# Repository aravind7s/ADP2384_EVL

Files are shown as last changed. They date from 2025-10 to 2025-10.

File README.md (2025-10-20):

# ADP2384_EVL

Hardware design files for a **12 V → 3.3 V @ 4 A** DC-DC buck converter based on the **Analog Devices ADP2384** designed using KiCad.

---

## 🧭 Overview

This project contains the complete design package — schematic, layout, and simulation files — for a compact, high-efficiency step-down converter using the ADP2384 synchronous buck regulator.  

---

## ⚙️ Board Specifications

| Parameter | Specification |
|---|---|
| Input Voltage | 12 V |
| Output Voltage | 3.3 V |
| Output Current | Up to 4 A |
| Regulator IC | ADP2384 |
| Board Dimensions | 35 mm × 40 mm |
| PCB Layers | 2 layers |
| Assembly | Single-sided |

---

*3D render of the ADP2384_EVL board (35 × 40 mm)*

*Front Side*

<p align="left">
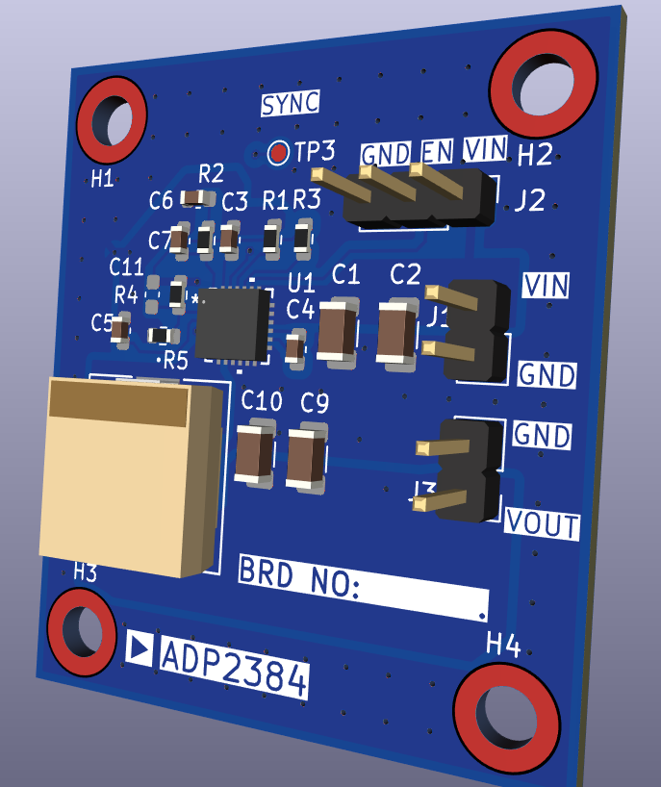
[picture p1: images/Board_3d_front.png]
3D View of the Board Front Side
  
</p>

*Back Side*

<p align="left">
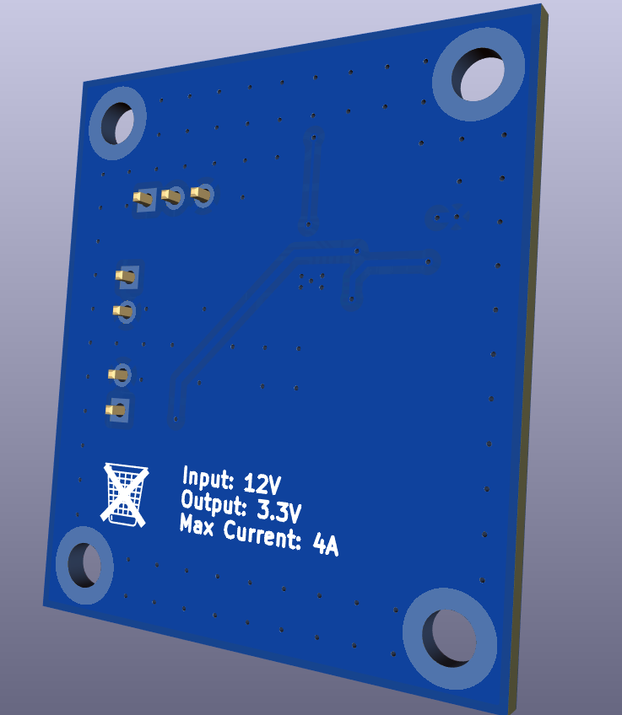
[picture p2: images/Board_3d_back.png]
3D View of the Board Back Side
  
</p>

---

## 📂 Repository Structure
/

├── Board_Files/ # Schematics, BOM, PCB layout and Gerbers

├── Simulation_Files/ # LTspice file

├── TechRef/ # Datasheets and application notes

├── images/ # Renders, photos, documentation images

├── LICENSE

└── README.md

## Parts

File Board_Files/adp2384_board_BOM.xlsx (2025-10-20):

S. No | Reference | Description | Mfg | Mfg Part No | Value | Qty | Footprint | Datasheet
1 | C1,C2 | Cap, Cer-X7R, 10uF, 25Vdc, 10%, 1206 | Samsung Electro-Mechanics | CL31B106KAHNNNE | 10uF | 2 | Capacitor_SMD:C_1206_3216Metric | https://product.samsungsem.com/mlcc/CL31B106KAHNNN.do
2 | C3 | Cap, Cer-X7R, 22nF, 100Vdc, 10%, 0603 | Murata Electronics | GCM188R72A223KA37J | 22nF | 1 | Capacitor_SMD:C_0603_1608Metric | https://pim.murata.com/en-sg/pim/details/?partNum=GCM188R72A223KA37%23
3 | C4 | Cap, Cer-X7R, 0.1uF, 50Vdc, 10%, 0603 | YAGEO | CC0603KRX7R9BB104 | 0.1uF | 1 | Capacitor_SMD:C_0603_1608Metric | yageo.com/en/Chart/Download/pdf/CC0603KRX7R7BB104
4 | C5 | Cap, Cer-X7R, 1uF, 16Vdc, 10%, 0603 | Samsung Electro-Mechanics | CL10B105KO8NNNC | 1uF | 1 | Capacitor_SMD:C_0603_1608Metric | https://weblib.samsungsem.com/mlcc/mlcc-ec-data-sheet.do?partNumber=CL10B105KO8NNN
5 | C6 | Cap, Cer-C0G, 1500pF, 50Vdc, 5%, 0603 | Murata Electronics | GRM1885C1H152JA01D | 1500pF | 1 | Capacitor_SMD:C_0603_1608Metric | https://pim.murata.com/en-eu/pim/details/?partNum=GRM1885C1H152JA01D
6 | C7 | Cap, Cer-C0G, 4.7pF, 50Vdc, +/-0.25pF, 0603 | YAGEO | CC0603CPNPO9BN4R7 | 4.7pF | 1 | Capacitor_SMD:C_0603_1608Metric | https://www.yageogroup.com/download/specsheet/CC0603CRNPO9BN4R7
7 | C9,C10 | Cap, Cer-X5R, 47uF, 10Vdc, 20%, 1206 | Murata Electronics | GRM31CR61A476ME15L | 47uF | 2 | Capacitor_SMD:C_1206_3216Metric | https://pim.murata.com/en-sg/pim/details/?partNum=GRM31CR61A476ME15%23
8 | J1,J3 | Conn, Header, Male, 1x2, 2.54mm, Vertical, TH | Adam Tech | PH1-02-UA | Conn_01x02 | 2 | Connector_PinHeader_2.54mm:PinHeader_1x02_P2.54mm_Vertical | https://app.adam-tech.com/products/download/data_sheet/201605/ph1-xx-ua-data-sheet.pdf
9 | J2 | Conn, Header, Male, 1x3, 2.54mm, Vertical, TH | Adam Tech | PH1-03-UA | Conn_01x03 | 1 | Connector_PinHeader_2.54mm:PinHeader_1x03_P2.54mm_Vertical | https://app.adam-tech.com/products/download/data_sheet/201605/ph1-xx-ua-data-sheet.pdf
10 | L1 | Ind, 3.3uH, 20%, 18.6A, 14.4mE, Shielded, SMD | Vishay Dale | IHLP4040DZER3R3M01 | 3.3uH | 1 | IHLP-4040DZ-01:IND_IHLP-4040DZ_VIS | https://www.vishay.com/docs/34193/ihlp-4040dz-01.pdf
11 | R1 | Res, Chip, 100k, 1%, 1/8W, AEC-Q200, 0603 | Vishay Dale | CRCW0603100KFKEA | 100k | 1 | Resistor_SMD:R_0603_1608Metric | https://www.vishay.com/docs/20035/dcrcwe3.pdf
12 | R2 | Res, Chip, 31.6k, 1%, 1/8W, AEC-Q200, 0603 | Vishay Dale | CRCW060331K6FKEA | 31.6k | 1 | Resistor_SMD:R_0603_1608Metric | https://www.vishay.com/docs/20035/dcrcwe3.pdf
13 | R3,R4 | Res, Chip, 10k, 1%, 1/8W, AEC-Q200, 0603 | Vishay Dale | CRCW060310K0FKEA | 10k | 2 | Resistor_SMD:R_0603_1608Metric | https://www.vishay.com/docs/20035/dcrcwe3.pdf
14 | R5 | Res, Chip, 2.21k, 1%, 1/8W, AEC-Q200, 0603 | Vishay Dale | CRCW06032K21FKEA | 2.21k | 1 | Resistor_SMD:R_0603_1608Metric | https://www.vishay.com/docs/20035/dcrcwe3.pdf
15 | U1 | IC, Power, 0.45V-20V, 0.6-18V, 4A, QFN-24 | Analog Devices Inc. | ADP2384ACPZN-R7 | ADP2384 | 1 | ADP2384:CP_24_12_ADI | https://www.analog.com/media/en/technical-documentation/data-sheets/ADP2384.pdf

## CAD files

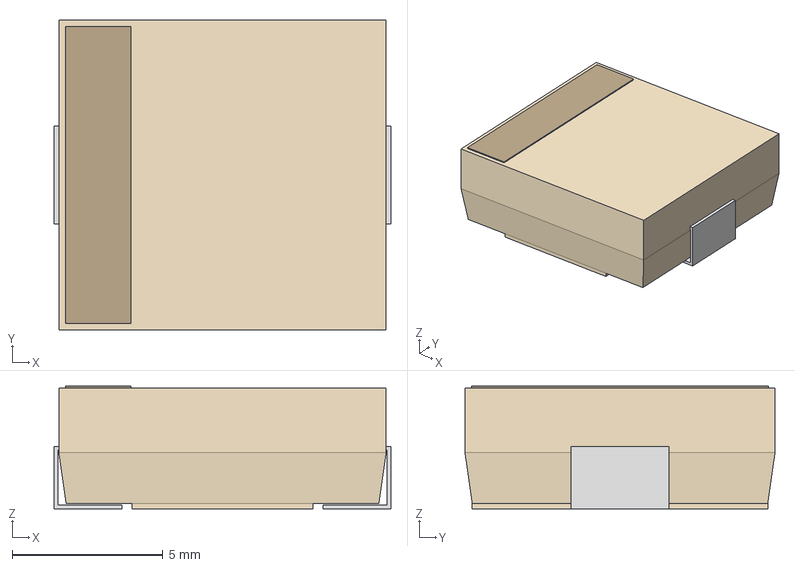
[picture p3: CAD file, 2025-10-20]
Board_Files/PartLibrary/IHLP4040DZER3R3M01/IND_IHLP-4040DZ_VIS.step
11.2 x 10.3 x 4.06 mm

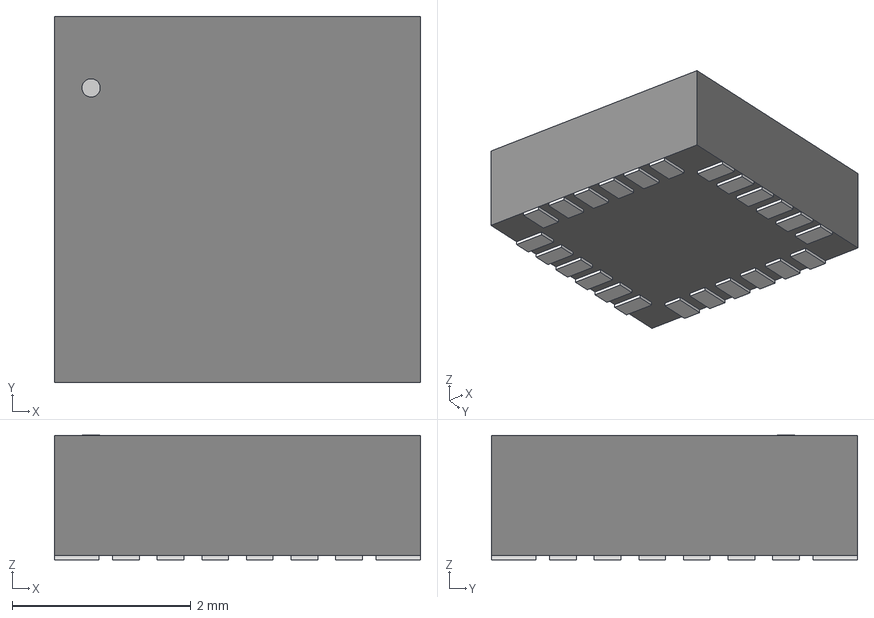
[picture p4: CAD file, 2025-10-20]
Board_Files/PartLibrary/ul_ADP2384ACPZN-R7/CP_24_12_ADI.step
4.10 x 4.10 x 1.40 mm

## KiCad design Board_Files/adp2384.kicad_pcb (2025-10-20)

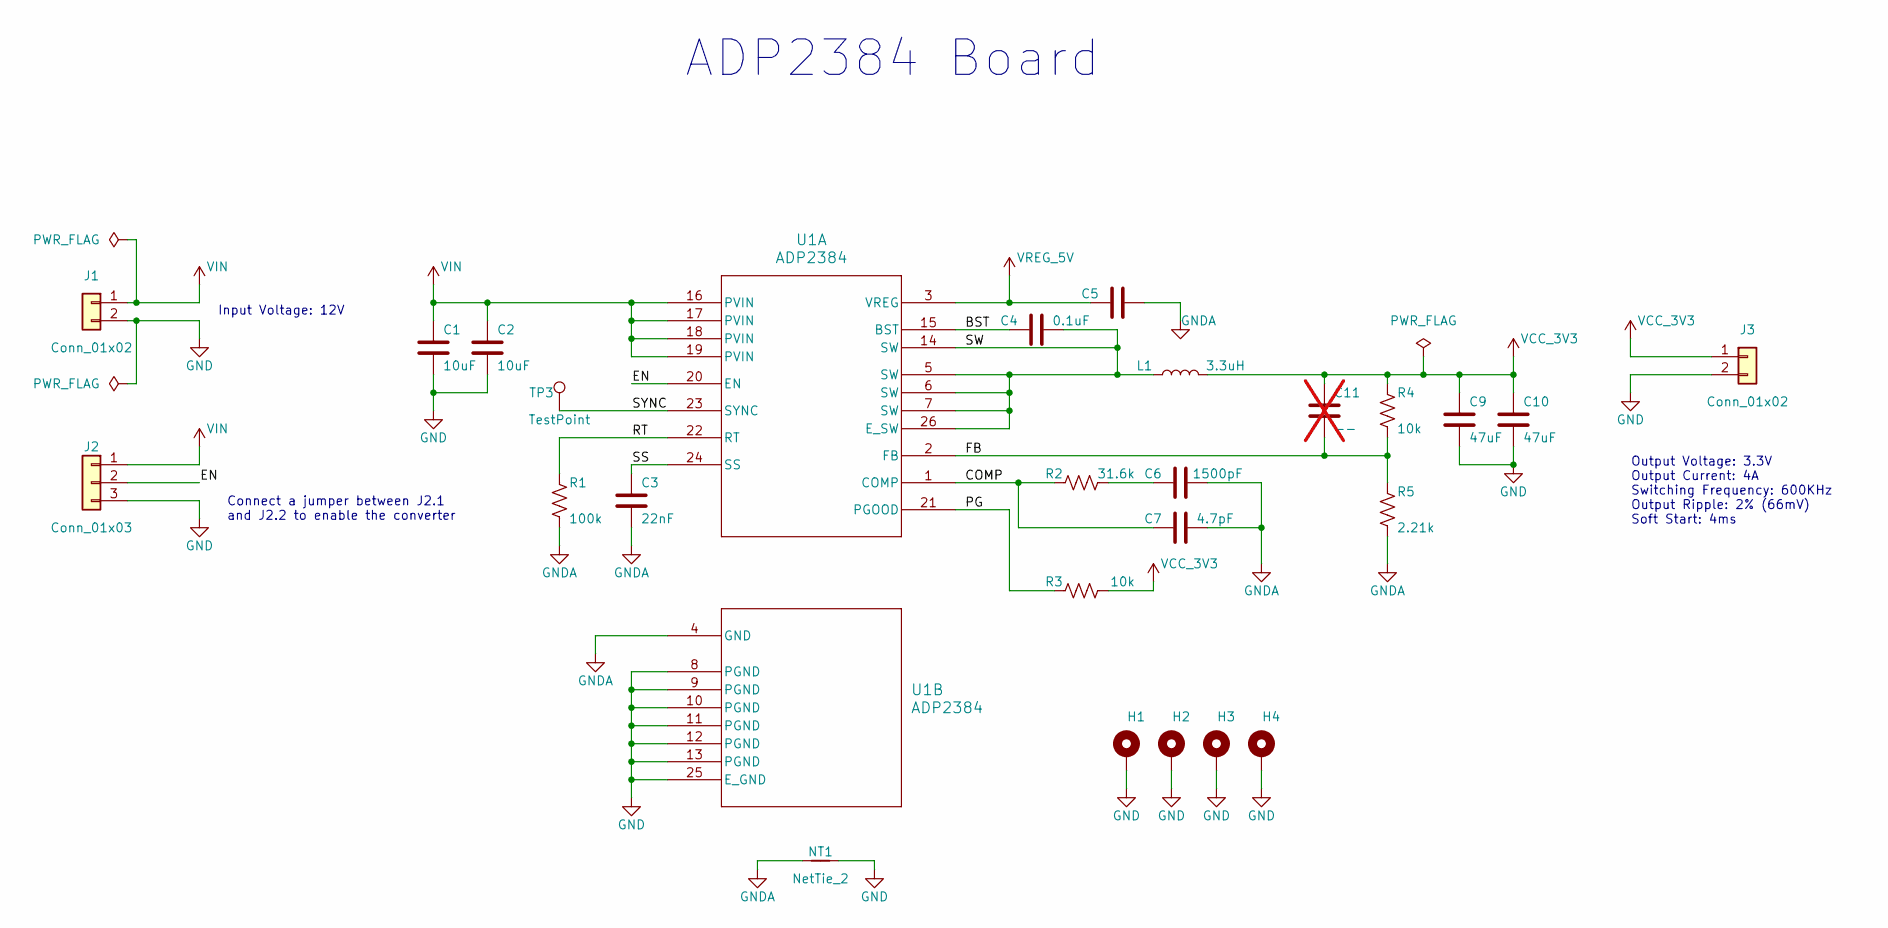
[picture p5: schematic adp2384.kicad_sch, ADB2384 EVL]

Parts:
C1, C2: 10uF; C_1206_3216Metric; Mfg Part No CL31B106KAHNNNE
C3: 22nF; C_0603_1608Metric; Mfg Part No GCM188R72A223KA37J
C4: 0.1uF; C_0603_1608Metric; Mfg Part No CC0603KRX7R9BB104
C5: 1uF; C_0603_1608Metric; Mfg Part No CL10B105KO8NNNC
C6: 1500pF; C_0603_1608Metric; Mfg Part No GRM1885C1H152JA01D
C7: 4.7pF; C_0603_1608Metric; Mfg Part No CC0603CPNPO9BN4R7
C9, C10: 47uF; C_1206_3216Metric; Mfg Part No GRM31CR61A476ME15L
C11: --; C_0603_1608Metric; Mfg Part No NA; not fitted
H1, H2, H3, H4: MountingHole_Pad; MountingHole_3.2mm_M3_DIN965_Pad_TopBottom; Mfg Part No NA
J1, J3: Conn_01x02; PinHeader_1x02_P2.54mm_Vertical; Mfg Part No PH1-02-UA
J2: Conn_01x03; PinHeader_1x03_P2.54mm_Vertical; Mfg Part No PH1-03-UA
L1: 3.3uH; IND_IHLP-4040DZ_VIS; Mfg Part No IHLP4040DZER3R3M01
NT1: NetTie_2; NetTie-2_THT_Pad0.3mm; Mfg Part No NA
R1: 100k; R_0603_1608Metric; Mfg Part No CRCW0603100KFKEA
R2: 31.6k; R_0603_1608Metric; Mfg Part No CRCW060331K6FKEA
R3, R4: 10k; R_0603_1608Metric; Mfg Part No CRCW060310K0FKEA
R5: 2.21k; R_0603_1608Metric; Mfg Part No CRCW06032K21FKEA
TP3: TestPoint; TestPoint_Pad_D1.0mm; Mfg Part No NA
U1: ADP2384; CP_24_12_ADI; Mfg Part No ADP2384ACPZN-R7

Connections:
/BST: C4.2, U1.15 (BST)
/COMP: C7.2, R2.1, U1.1 (COMP)
/EN: J2.2, U1.20 (EN)
/FB: C11.1, R4.2, R5.1, U1.2 (FB)
/PG: R3.1, U1.21 (PGOOD)
/RT: R1.1, U1.22 (RT)
/SS: C3.2, U1.24 (SS)
/SW: C4.1, L1.1, U1.5 (SW), U1.6 (SW), U1.7 (SW), U1.14 (SW), U1.26 (E_SW)
/SYNC: TP3.1, U1.23 (SYNC)
GND: C1.1, C2.1, C9.1, C10.1, H1.1, H2.1, H3.1, H4.1, J1.2, J2.3, J3.2, NT1.2, U1.8 (PGND), U1.9 (PGND), U1.10 (PGND), U1.11 (PGND), U1.12 (PGND), U1.13 (PGND), U1.25 (E_GND)
GNDA: C3.1, C5.1, C6.1, C7.1, NT1.1, R1.2, R5.2, U1.4 (GND)
unnamed: C6.2, R2.2
VCC_3V3: C9.2, C10.2, C11.2, J3.1, L1.2, R3.2, R4.1
VIN: C1.2, C2.2, J1.1, J2.1, U1.16 (PVIN), U1.17 (PVIN), U1.18 (PVIN), U1.19 (PVIN)
VREG_5V: C5.2, U1.3 (VREG)

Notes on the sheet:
ADP2384 Board
Output Voltage: 3.3V Output Current: 4A Switching Frequency: 600KHz Output Ripple: 2% (66mV) Soft Start: 4ms
Connect a jumper between J2.1 and J2.2 to enable the converter
Input Voltage: 12V

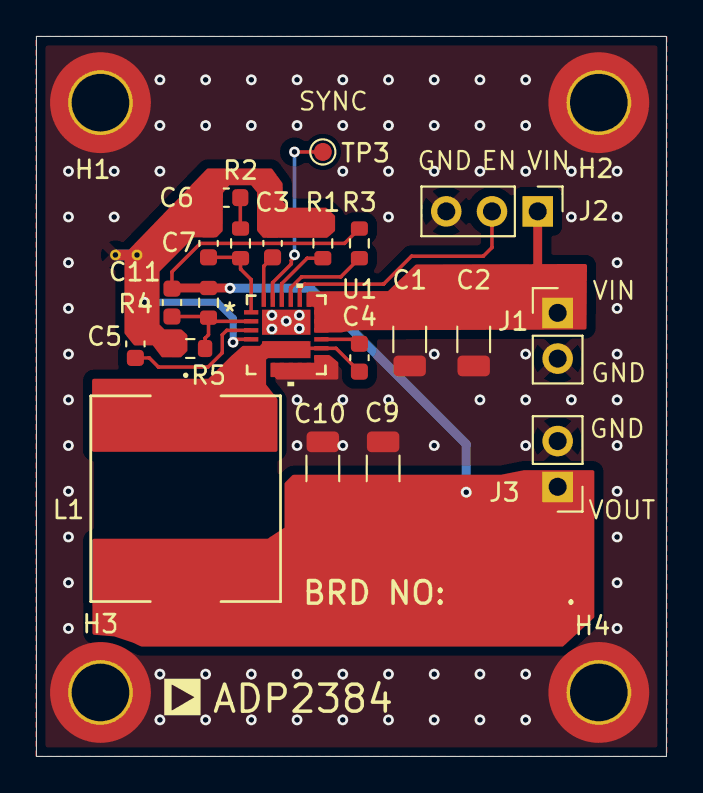
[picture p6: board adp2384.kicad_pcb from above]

Board: 2 copper layers, 35.0 x 40.0 mm, 26 parts (0 on the bottom side), 15 nets.

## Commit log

2025-10-20 First Release
    Schematics, LTSpice Simulation, Layout, and Gerber Files uploaded.
    [CP_24_12_ADI.step, IND_IHLP-4040DZ_VIS.step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]
2025-10-20 Update A1 Release files
    1. Added design information in Schematics.
    2. BOM generated.
    3. Updated the library path to align with the current folder structure.
    4. Added 3D board file images.
    5. Updated README.
    [adp2384.kicad_pcb, adp2384.kicad_sch]
2025-10-20 Updated BOM
    Removed the DNP components
    [adp2384_board_BOM.xlsx]
